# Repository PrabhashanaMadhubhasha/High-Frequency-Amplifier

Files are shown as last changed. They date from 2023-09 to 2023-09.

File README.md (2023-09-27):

# High-Frequency-Amplifier
Engineered to elevate audio signals, this device tackles low input high frequency amplitudes by prioritizing signal power and signal-to-noise ratio enhancement. It deploys a voltage amplifier as a pre-amplifying stage to bolster the input sine wave’s amplitude.

## Elevating Sound Quality

In the realm of electronics, amplifiers serve as the backbone of audio systems. The quest for an amplifier that marries power efficiency with sonic clarity is a relentless pursuit. In this article, we explore the intricacies of high-frequency amplifiers, focusing on the Class AB amplifier, system modeling, simulation results, PCB design, enclosure, and future possibilities. Let's dive into the world of high-fidelity sound amplification.

## Class AB Amplifier: The Powerhouse

At the heart of our high-frequency amplifier project lies the Class AB amplifier, a workhorse renowned for its efficiency and fidelity. Its ability to operate efficiently while minimizing power wastage during idle periods sets it apart from Class A amplifiers, which draw constant current. Moreover, it mitigates the crossover distortion often found in Class B amplifiers. In our project, it's the key to delivering robust, distortion-free sound.

## System Modeling: Precision in Components

Selecting the right components is crucial. We've opted for the BC547 transistor for its impressive characteristics, particularly its high transition frequency, ideal for the Common Emitter amplifier configuration. In the power amplification stage, Complementary Symmetry pairs - the TIP31 and TIP32 transistors - shine, offering robust performance and thermal stability.

## Simulation Results: Validating Performance

Our design undergoes rigorous simulations to ensure it meets real-world demands. The results are reassuring: a bandwidth spanning 20 kHz to 360 kHz, minimal distortion, and optimal impedance. These simulations validate the efficiency and fidelity of our Class AB amplifier.

## PCB Design and Enclosure: Form and Function

The PCB layout is carefully crafted to accommodate high-frequency applications and manage temperature fluctuations effectively. Strategic placement of power-related transistors ensures efficient heat dissipation and signal flow. The enclosure, at 110 × 62 × 107 mm³, offers strength and ventilation to prevent overheating during extended use.

## Final Results: Success in Specifications

Our project culminates in evaluating the final results, which align seamlessly with our objectives. Bandwidth, voltage gain, impedance levels, and operational temperatures all meet our specifications. The Class AB amplifier shines as the linchpin, ensuring efficiency and fidelity.

## Future Possibilities: Sonic Innovation

Looking ahead, the world of high-frequency amplification holds exciting possibilities. Exploring differential amplifiers for noise reduction and complementary symmetry Darlington pairs for enhanced power gain could further elevate sound quality.

## Acknowledgment: A Collective Effort

The journey from concept to realization is a collaborative one. We extend our heartfelt appreciation to our project guides, Mr. Tharindu, Ms. Yomali, and Ms. Amashi, whose expertise guided us. Every contributor, no matter how small their role, played a part in our project's success.

Our high-frequency amplifier project epitomizes the harmony between efficiency and audio clarity, embodied by the Class AB amplifier. It showcases the potential of electronics and engineering in achieving sonic excellence, reaffirming the limitless boundaries of innovation.

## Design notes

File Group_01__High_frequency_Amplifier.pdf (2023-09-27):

## High Frequency Amplifier

[EN2091] Analog Lab Project

Group O1 : Intake 20

Department of Eletronic and Telecomunication Engineering University of Moratuwa

2023-02-27


Group 01, semester 03 (ENTC, UoM) | High Frequency Amplifier | 2023-02-27 | 1 / 29

## Outline

1 Introduction

2 Functionality

3 System Model

4 Schematic

5 Simulation Results

6 PCB Design

7 Enclouser Design

8 Final Results

9 Future Works

10 Acknowledgment

Group 01, semester 03 (ENTC, UoM) | High Frequency Amplifier | 2023-02-27 | 2 / 29

## Introduction

The objective of this project is to create a distortion free output for an input signal with a single tone sine wave of 0.1 V peak to peak voltage.
The amplifier should be compatible with 8 Ω speaker and 12 V power source.
Group 01, semester 03 (ENTC, UoM) | High Frequency Amplifier | 2023-02-27 | 3 / 29

## Outline

1 Introduction

2 Functionality

3 System Model

4 Schematic

5 Simulation Results

6 PCB Design

7 Enclouser Design

8 Final Results

9 Future Works

10 Acknowledgment

Group 01, semester 03 (ENTC, UoM) | High Frequency Amplifier | 2023-02-27 | 4 / 29

## Functionality

The low amplitude of the input signal is insufficient for speaker action. The signal power and signal-to-noise ratio must then be increased. When amplitudes are tiny, the noise effect will be very strong.
The input sine wave’s amplitude should be increased first, with a voltage amplifier used as a pre-Amplifying stage.

When driving the output signal to a headset, a high power gain is preferred. The pre-amplifier can only provide 50 mA of current, which is not enough to operate the speaker.
In order to produce a power amplification, we have therefore chosen to use a class AB amplifier after the voltage amplifier.
Group 01, semester 03 (ENTC, UoM) | High Frequency Amplifier | 2023-02-27 | 5 / 29

## Functionality - Stage A : Pre-Amplifier

The BJT transistor can be used in three different configurations as a Voltage Amplifier.

Common Collector
Common Emitter
Common Base

The Common Emitter configuration has been selected.

when compared to the other two configuration techniques, maximum power gain can get through this configuration.

Group 01, semester 03 (ENTC, UoM) | High Frequency Amplifier | 2023-02-27 | 6 / 29

## Functionality - Stage B : Power-Amplifier

There are several classes of transistor-based power amplifiers[Tob07].

Class A

Class B
Class AB

Class C

The Class AB Power Amplifier has been selected.

This configuration eliminates crossover distortion as the input signal won’t be used to bias junctions, and the Q point operates at the edge of the cutoff and active regions, making this type more power efficient.

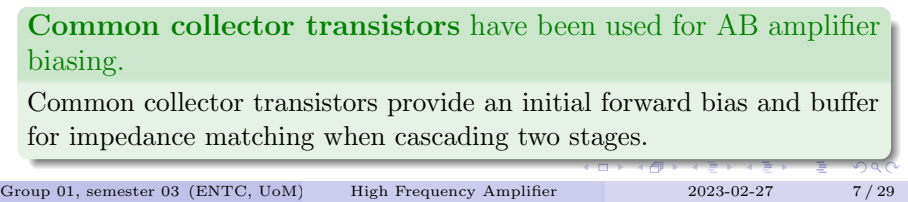
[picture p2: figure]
biasing.

Common collector transistors have been used for AB amplifier

Common collector transistors provide an initial forward bias and buffer for impedance matching when cascading two stages.

Group 01, semester 03 (ENTC, UoM) | High Frequency Amplifier | 2023-02-27 | 7 / 29

## Functionality - Block Diagram

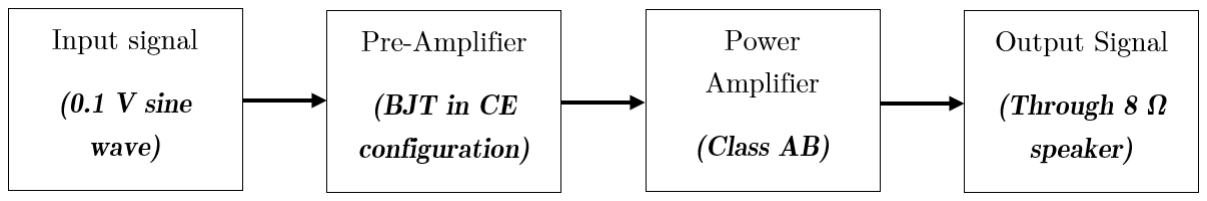
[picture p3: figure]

Figure: Block Diagram

Group 01, semester 03 (ENTC, UoM) | High Frequency Amplifier | 2023-02-27 | 8 / 29

## Outline

1 Introduction

2 Functionality

3 System Model

4 Schematic

5 Simulation Results

6 PCB Design

7 Enclouser Design

8 Final Results

9 Future Works

10 Acknowledgment

Group 01, semester 03 (ENTC, UoM) | High Frequency Amplifier | 2023-02-27 | 9 / 29

## System Model : Stage 01 : Pre- Amplifier

Transition frequency and current gain of the most used transistors for the pre-amplifying stage
Characteristic | BC107 [SEM97b] | BC547 | 2N2222 [SEM97a]
Trans. Freq. Gain | 150 110-450 | 300 110-800 | 250 30-300

BC547 transistor has been used as the voltage Amplifier.

The BC547 transistor is the highest transition frequency and has high current gain for the voltage amplifying stage. It also has fast switching and fast responding time, making it an ideal choice for the Common Emitter amplifier.

Group 01, semester 03 (ENTC, UoM) | High Frequency Amplifier | 2023-02-27 | 10 / 29

## System Model : Stage 01 : Pre- Amplifier : Initial Calculations

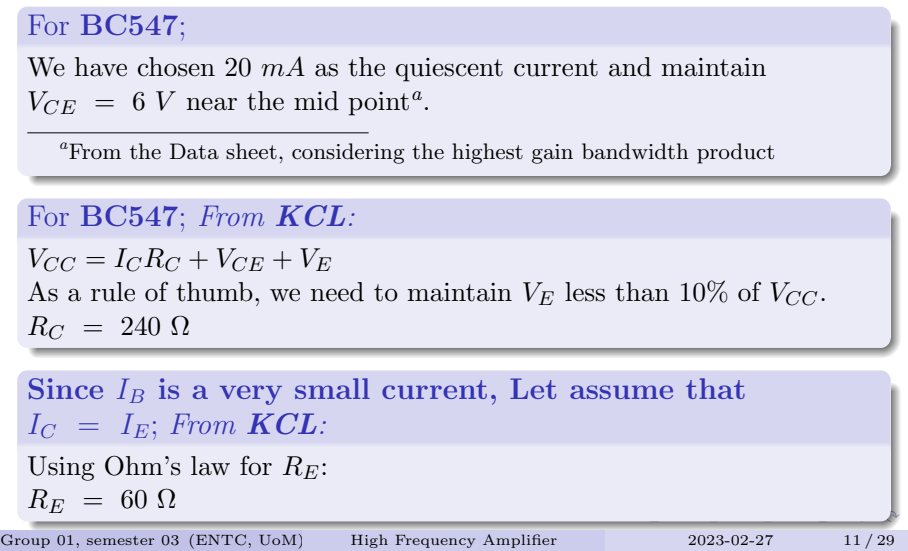
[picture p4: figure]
For BC547;; VCE = 6 V near the mid pointa; For BC547; From KCL:; VCC = ICRC + VCE + VE; IC = IE; From KCL:; Using Ohm’s law for RE: RE = 60 Ω

We have chosen 20 mA as the quiescent current and maintain

aFrom the Data sheet, considering the highest gain bandwidth product

As a rule of thumb, we need to maintain VE less than 10% of VCC.

Since IB is a very small current, Let assume that

Group 01, semester 03 (ENTC, UoM) | High Frequency Amplifier | 2023-02-27 | 11 / 29

## System Model : Stage 02 : Power - Amplifier

For AB class operation, a Complementary Symmetry pair is also required.
We have chosen the complementary symmetry pair of TIP31 and TIP32, which has a maximum collector current of 5 A, due to the requirement for through-hole transistors.

Thermal Stability

To guarantee the thermal stability of an AB push-pull amplifier, resistors are required. As a result, we use resistors with 2.2 Ω resistance to decrease power dissipation as well.

Thermal Management

For Common Collector and class AB amplifiers, respectively, 2 W and

### 5 W resistors are used

Group 01, semester 03 (ENTC, UoM) | High Frequency Amplifier | 2023-02-27 | 12 / 29

## Outline

1 Introduction

2 Functionality

3 System Model

4 Schematic

5 Simulation Results

6 PCB Design

7 Enclouser Design

8 Final Results

9 Future Works

10 Acknowledgment

Group 01, semester 03 (ENTC, UoM) | High Frequency Amplifier | 2023-02-27 | 13 / 29

## Schematic

We modified our computations to use component values in a practical manner.

RC = 220 Ω, RE = 68 Ω, RB2 = 2 kΩ

F or input coupling capacitor : 4.7 µF

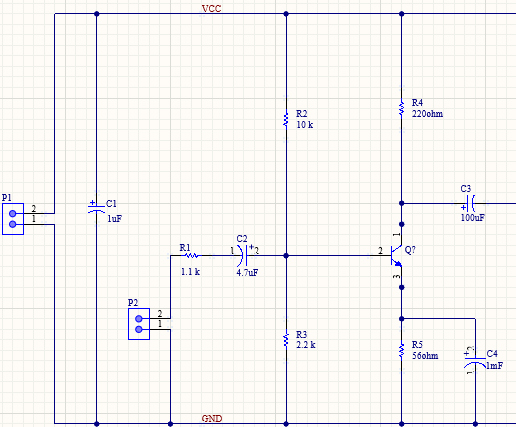
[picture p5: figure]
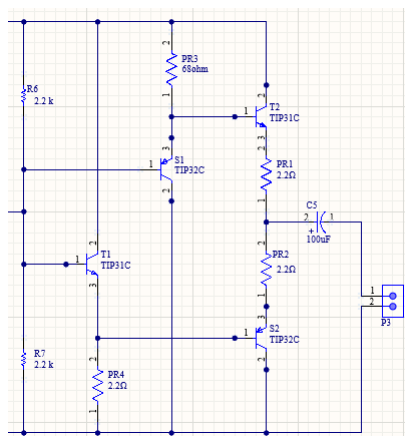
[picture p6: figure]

Figure: Voltage Amplifier | Figure: Power Amplifier
Group 01, semester 03 (ENTC, UoM) | High Frequency Amplifier | 2023-02-27 | 14 / 29

## Schematic : Entire Schematic

The Breadboard implementation requires changing values to account for wire resistance.
Therefore to maintain the Q point in the linear region in the output characteristic, RE = 56 Ω and RB2 = 2.2 kΩ.

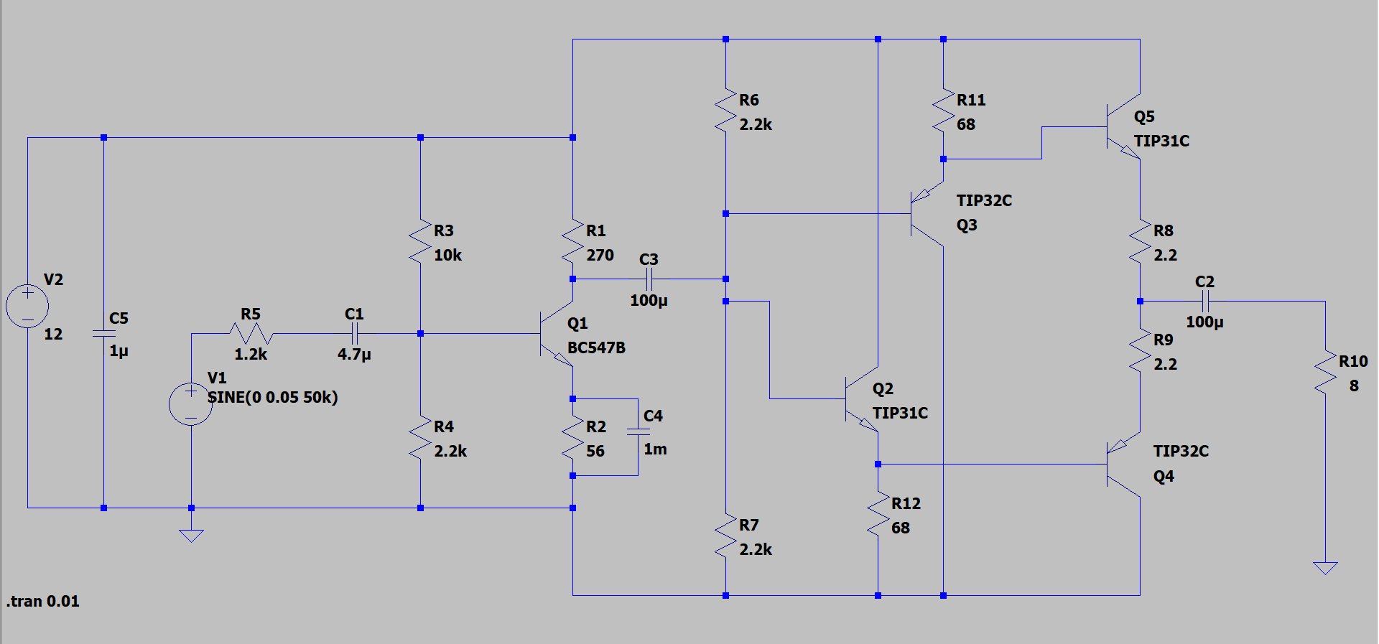
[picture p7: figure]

Figure: LTspiceXVII

Group 01, semester 03 (ENTC, UoM) | High Frequency Amplifier | 2023-02-27 | 15 / 29

## Outline

1 Introduction

2 Functionality

3 System Model

4 Schematic

5 Simulation Results

6 PCB Design

7 Enclouser Design

8 Final Results

9 Future Works

10 Acknowledgment

Group 01, semester 03 (ENTC, UoM) | High Frequency Amplifier | 2023-02-27 | 16 / 29

## Simulation Results

With Load(8 Ω)

Input Current (pk to pk) : 64.39 µA

Bandwidth : 212 kHz
Output Voltage (pk to pk) : 1.556 V

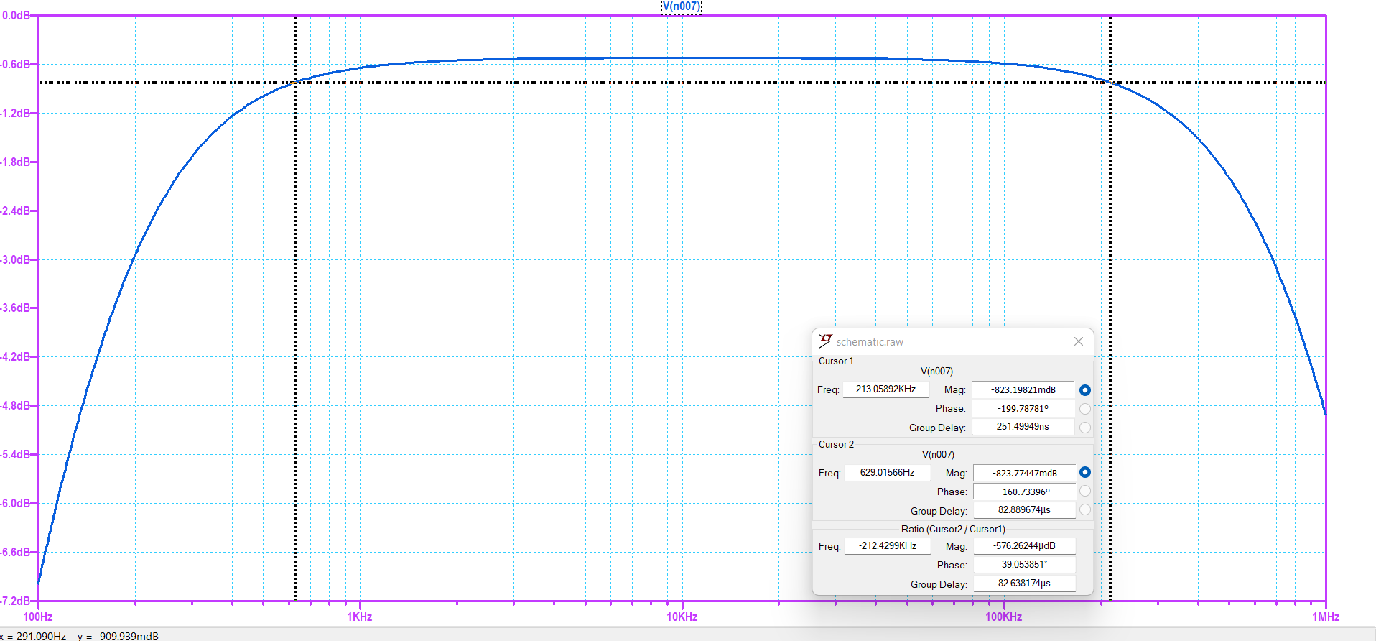
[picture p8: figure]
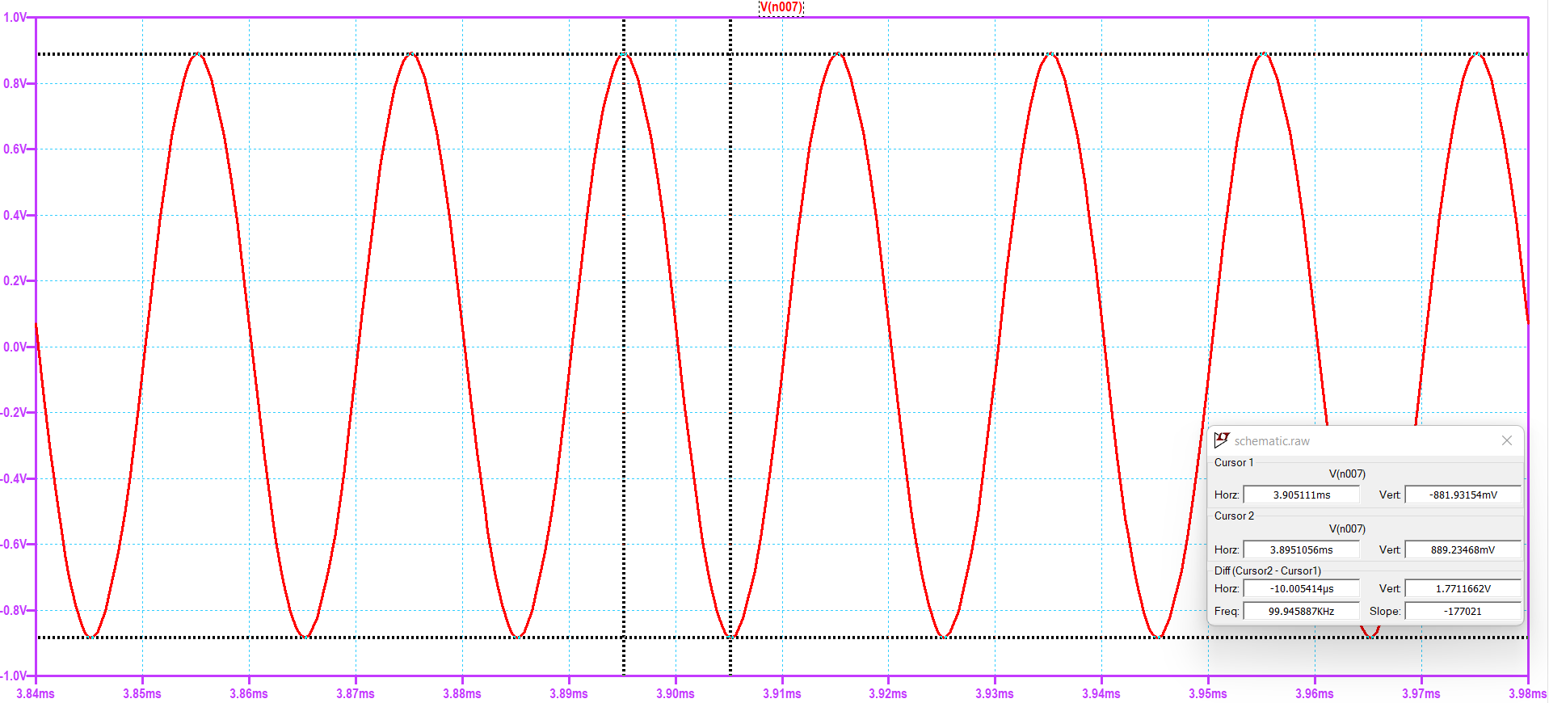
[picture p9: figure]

Figure: Output Signal | Figure: Bandwidth
Group 01, semester 03 (ENTC, UoM) | High Frequency Amplifier | 2023-02-27 | 17 / 29

## Outline

1 Introduction

2 Functionality

3 System Model

4 Schematic

5 Simulation Results

6 PCB Design

7 Enclouser Design

8 Final Results

9 Future Works

10 Acknowledgment

Group 01, semester 03 (ENTC, UoM) | High Frequency Amplifier | 2023-02-27 | 18 / 29

## PCB Design

The PCB layout is designed to accommodate high-frequency applications while minimizing temperature increase.

1 | The angle between two adjacent current passing lines is taken at an obtuse angle to minimize interference.
2 | Two layers in the PCB are used to reduce high-frequency noise and ground the signal as rapidly as possible.
3 | The two transistors of T IP31C and T IP32C are power related, so they are placed in the four corners of the PCB board.

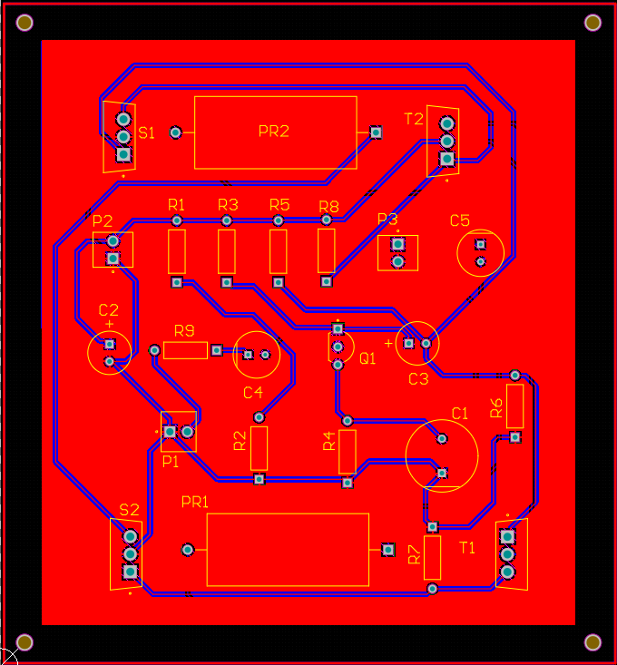
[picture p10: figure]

Figure: PCB - Top

Group 01, semester 03 (ENTC, UoM) | High Frequency Amplifier | 2023-02-27 | 19 / 29

## Outline

1 Introduction

2 Functionality

3 System Model

4 Schematic

5 Simulation Results

6 PCB Design

7 Enclouser Design

8 Final Results

9 Future Works

10 Acknowledgment

Group 01, semester 03 (ENTC, UoM) | High Frequency Amplifier | 2023-02-27 | 20 / 29

## Enclosure Design

1 | The enclosure is 110 × 62 × 107 mm³ and consists of an upper half and a lower half joined by eight tiny nails.
2 | The thickness of the walls is 2 mm to achieve strength and lightness, and vents are positioned to allow heated air to flow out.
3 | The SPST switch and red LED are placed on the backside, and three ports are connected to the lower part of the enclosure for easy maintenance.

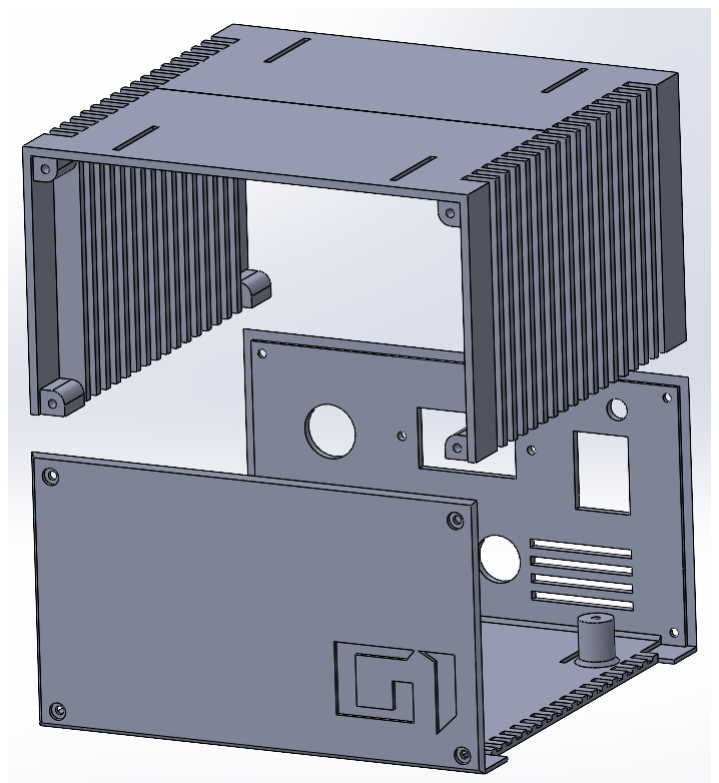
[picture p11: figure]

Figure: Enclosure

Group 01, semester 03 (ENTC, UoM) | High Frequency Amplifier | 2023-02-27 | 21 / 29

## Final Enclosure Design

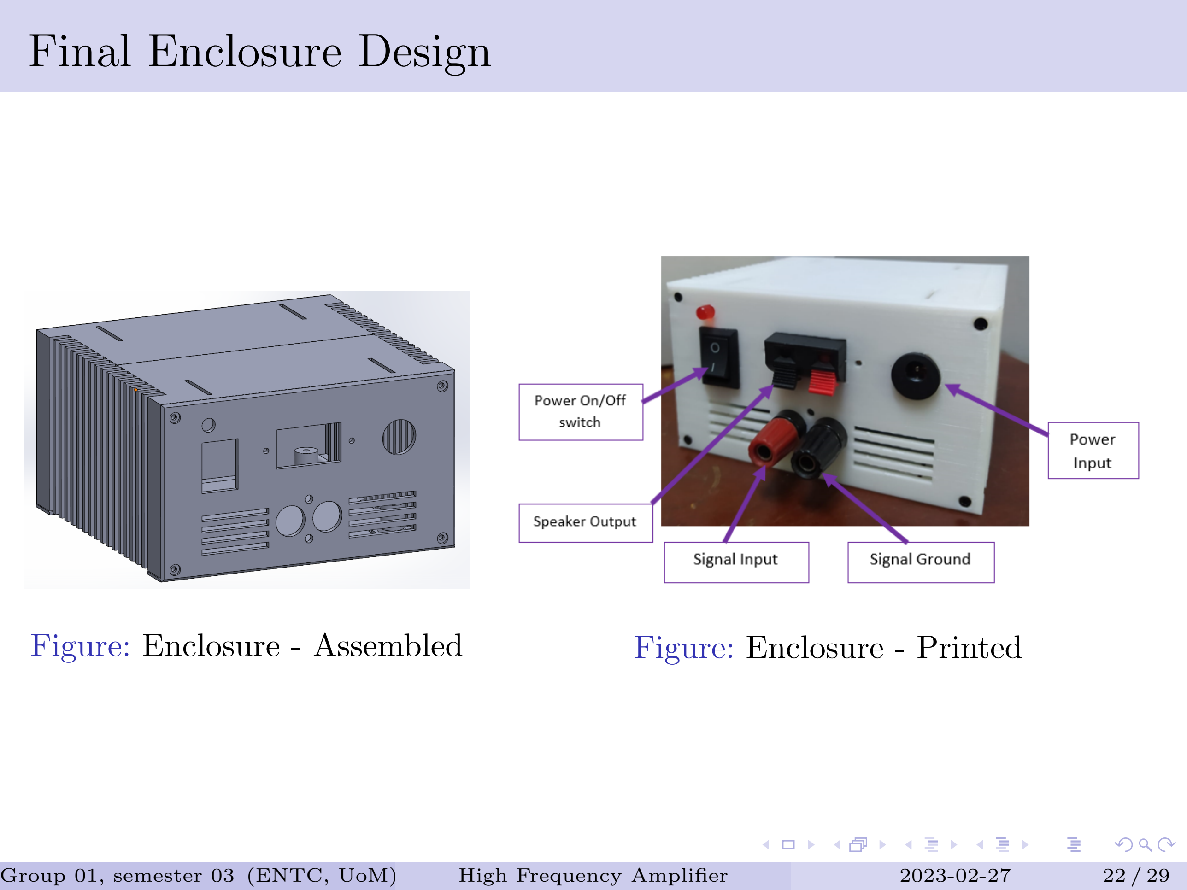
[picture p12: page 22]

Figure: Enclosure - Assembled | Figure: Enclosure - Printed
Group 01, semester 03 (ENTC, UoM) | High Frequency Amplifier | 2023-02-27 | 22 / 29

## Outline

1 Introduction

2 Functionality

3 System Model

4 Schematic

5 Simulation Results

6 PCB Design

7 Enclouser Design

8 Final Results

9 Future Works

10 Acknowledgment

Group 01, semester 03 (ENTC, UoM) | High Frequency Amplifier | 2023-02-27 | 23 / 29

## Final Results

SYM. | PARA. | COND. | MIN. TYP. | | MAX. UNI.
BW | Bandwidth | RL = 8 Ω | 20 | | 360 | kHz
Avo Av | Voltage Gain Voltage Gain | RL = ∞ RL = 8 Ω | | 27.5 26.1 | | dB dB
Rin Rout | Input Impedance Output Impedance | RL = ∞ RS = 0 | | 1.55 12 | | kΩ Ω
Pout | Output Power | RL = 8 Ω | 0.225 | 0.25 | 0.33 | W
To | Operation Temperature | RL = 8 Ω | 25 | | 32 | ◦C
Group 01, semester 03 (ENTC, UoM) | High Frequency Amplifier | 2023-02-27 | 24 / 29

## Outline

1 Introduction

2 Functionality

3 System Model

4 Schematic

5 Simulation Results

6 PCB Design

7 Enclouser Design

8 Final Results

9 Future Works

10 Acknowledgment

Group 01, semester 03 (ENTC, UoM) | High Frequency Amplifier | 2023-02-27 | 25 / 29

## Future Works

Differential Amplifier

To further reduce the potential for noise, we could use constant current differential amplifier that utilizes transistors in place of a voltage amplifie

Complementary Symmetry Darling ton Pairs

Transistors with Darling-ton pairs can improve the power gain of a high frequency amplifier, but cost concerns prevent implementation.

Group 01, semester 03 (ENTC, UoM) | High Frequency Amplifier | 2023-02-27 | 26 / 29

## Outline

1 Introduction

2 Functionality

3 System Model

4 Schematic

5 Simulation Results

6 PCB Design

7 Enclouser Design

8 Final Results

9 Future Works

10 Acknowledgment

Group 01, semester 03 (ENTC, UoM) | High Frequency Amplifier | 2023-02-27 | 27 / 29

## Acknowledgement

The success of this project was dependent on various factors, one of which was the guidance and assistance of numerous individuals. We express our utmost gratitude to our project guides, Mr. Tharindu, Ms. Yomali, and Ms. Amashi, whose unwavering dedication and keen interest in our work helped in the successful completion of our project. Furthermore,we would like to thank everyone who contributed even in small ways to the success of this endeavor.

Group 01, semester 03 (ENTC, UoM) | High Frequency Amplifier | 2023-02-27 | 28 / 29

## References

DISCRETE SEMICONDUCTORS, 2n2222; 2n2222a.

, Bc107; bc108; bc109.

Paul Tobin, Operational amplifier characteristics, PSpice for Circuit Theory and Electronic Devices, Springer, 2007,
pp. 127–154.
Group 01, semester 03 (ENTC, UoM) | High Frequency Amplifier | 2023-02-27 | 29 / 29

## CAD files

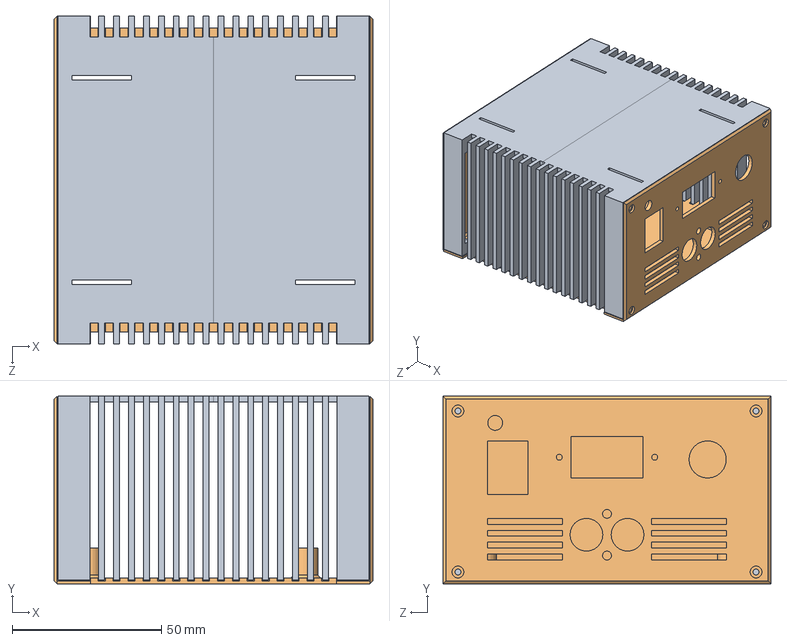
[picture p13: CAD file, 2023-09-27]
Enclosure Design/Assembly.SLDASM
107.0 x 63.0 x 110.0 mm
P2_new
P1_new

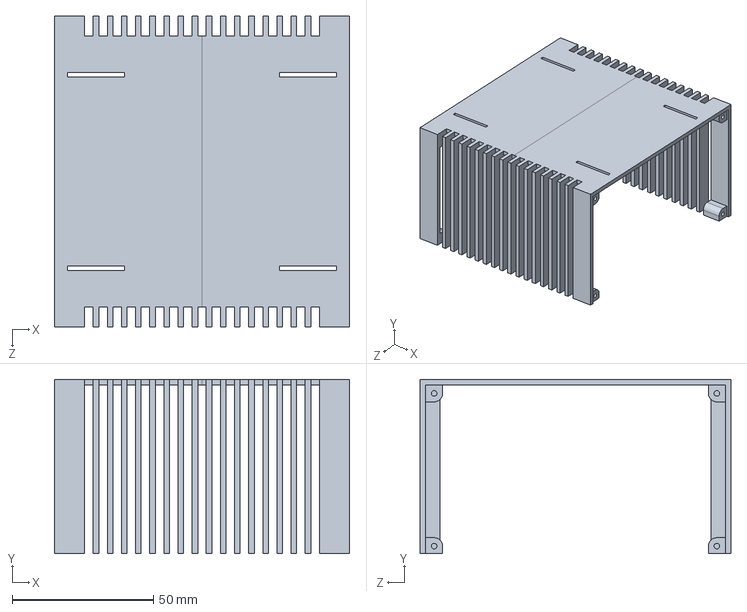
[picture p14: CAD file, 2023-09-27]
Enclosure Design/P2_new.SLDPRT
104.4 x 61.7 x 110.0 mm

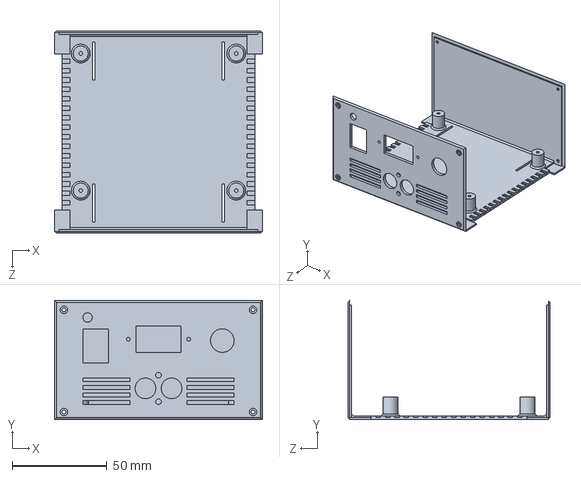
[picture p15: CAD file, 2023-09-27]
Enclosure Design/P1_new.SLDPRT
110.0 x 63.0 x 107.0 mm
